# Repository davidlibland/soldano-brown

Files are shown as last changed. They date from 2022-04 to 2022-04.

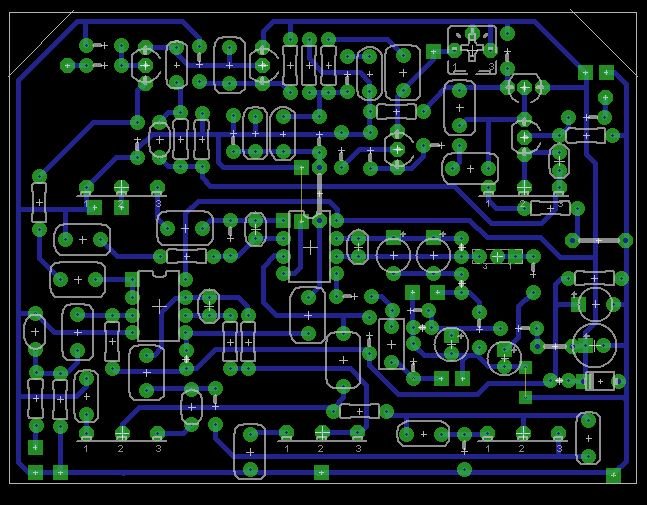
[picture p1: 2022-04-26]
SLO+MICRO.jpeg

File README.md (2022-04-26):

# Soldano BSIAB
This repo contains schematics and parts lists for a soldano clone based on the Brown Sound in a Box (BSIAB) pedal. It relies on cascading push-pull jfets.

It fits this enclosure: https://www.taydaelectronics.com/hardware/enclosures/matte-white-pedalpcb-125b-bare-drilled-enclosure-type-5-1.html

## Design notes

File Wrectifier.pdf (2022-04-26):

# Wrectifier

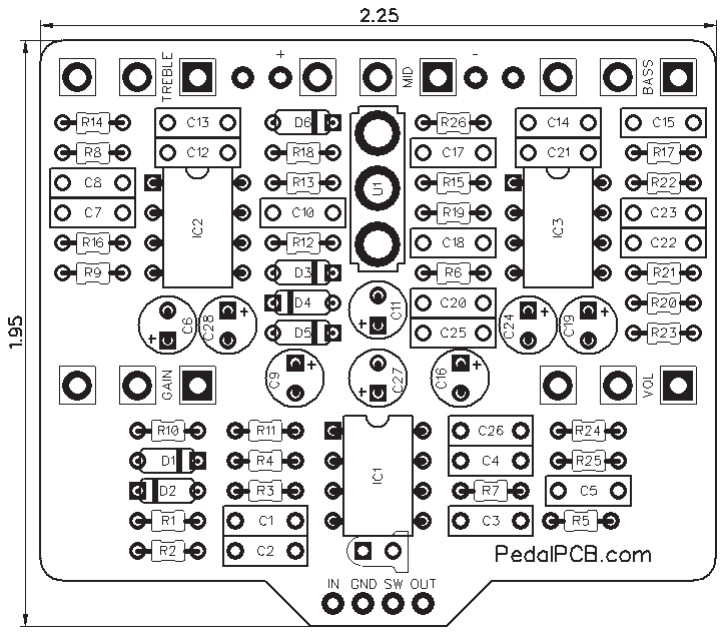
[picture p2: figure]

Copyright © 2017 - PedalPCB.com

R1 | 1M
R2 | 1K
R3 | 470K
R4 | 10K
R5 | 470K
R6 | 470K
R7 | 1K
R8 | 470K
R9 | 10K
R10 1K
R11 47K
R12 100K
R13 1K
R14 470K
R15 47K
R16 4K7
R17 1K
R18 10K
R19 47K

R20 33K
R21 33K
R22 680K
R23 10K
R24 10K
R25 10K
R26 4K7

Semiconductors
IC1 TL072
IC2 TL072
IC3 TL072
D1 | 1N4148
D2 | 1N4148
D3 | 1N4148
D4 | 1N4148
D5 | 1N4148
D6 | 1N5817
D7 | 3mm LED

Potentiometers
VOL | A100K
GAIN | A100K
BASS | C100K
MID | A100K
TREBLE | A50K

Revision 02.23.19

Resistors
C1 | 220nF
C2 | 220pF
C3 | 33nF
C4 | 560pF
C5 | 220nF
C6 | 1uF
C7 | 220pF
C8 | 220nF
C9 | 1uF
C10 220pF
C11 1uF
C12 4.7nF
C13 47nF
C14 47nF
C15 100nF
C16 1uF
C17 470pF
C18 47nF
C19 1uF

C20 100nF
C21 47nF
C22 1nF
C23 330pF
C24 1uF
C25 4.7nF
C26 10nF
C27 100uF
C28 10uF

Capacitors

Switches
Vintage/Modern SPDT Toggle

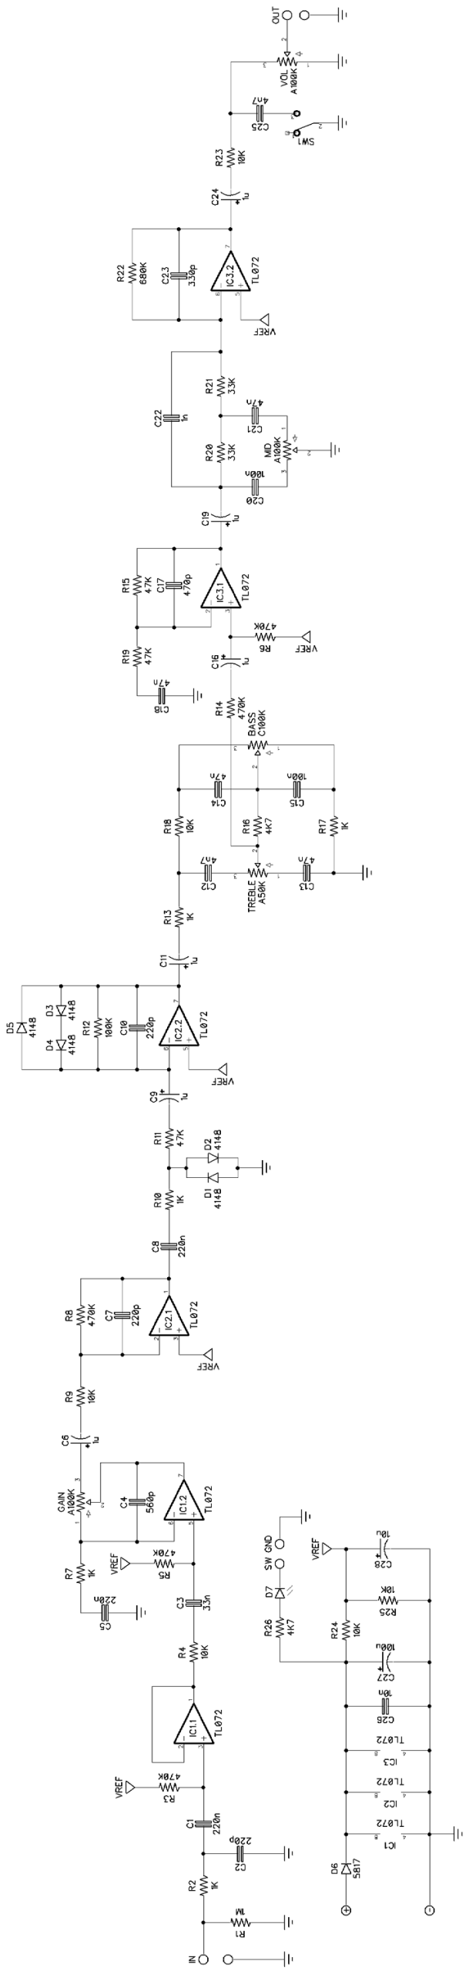
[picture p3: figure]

# Wrectifier

Copyright © 2017 - PedalPCB.com

# Wiring Diagram

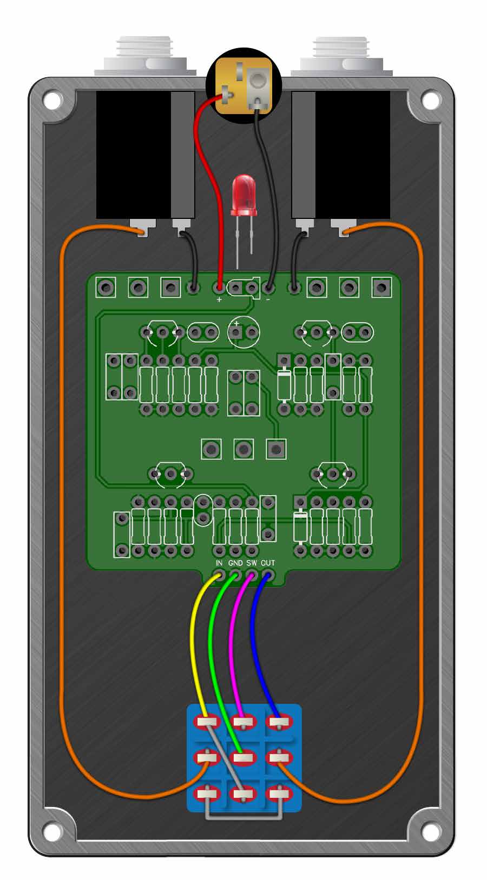
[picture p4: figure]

# Drill Template

# 4S125B enclosure with top mounted jacks

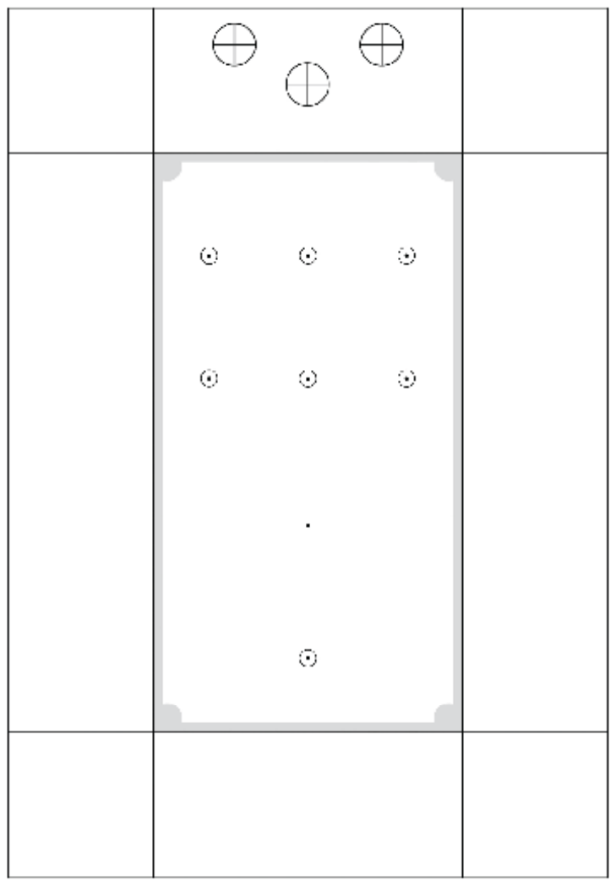
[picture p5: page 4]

5 x 1K
2 x 4K7
6 x 10K
2 x 33K
3 x 47K
1 x 100K
5 x 470K
1 x 680K
1 x 1M

3 x 220pF
1 x 330pF
1 x 470pF
1 x 560pF
1 x 1nF
2 x 4.7nF
1 x 10nF
1 x 33nF
4 x 47nF
2 x 100nF
3 x 220nF
6 x 1uF
1 x 10uF
1 x 100uF

3 x TL072

5 x 1N4148
1 x 1N5817

1 x 3mm LED

1 x A50K
3 x A100K
1 x C100K
Resistors (1/8W) | Capacitors | Semiconductors | Potentiometers

# Bill of Materials

1 x SPDT

Switches

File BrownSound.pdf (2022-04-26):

# BSIAB2 (Brown Sound In A Box - Version2) Design by Ed Guidry

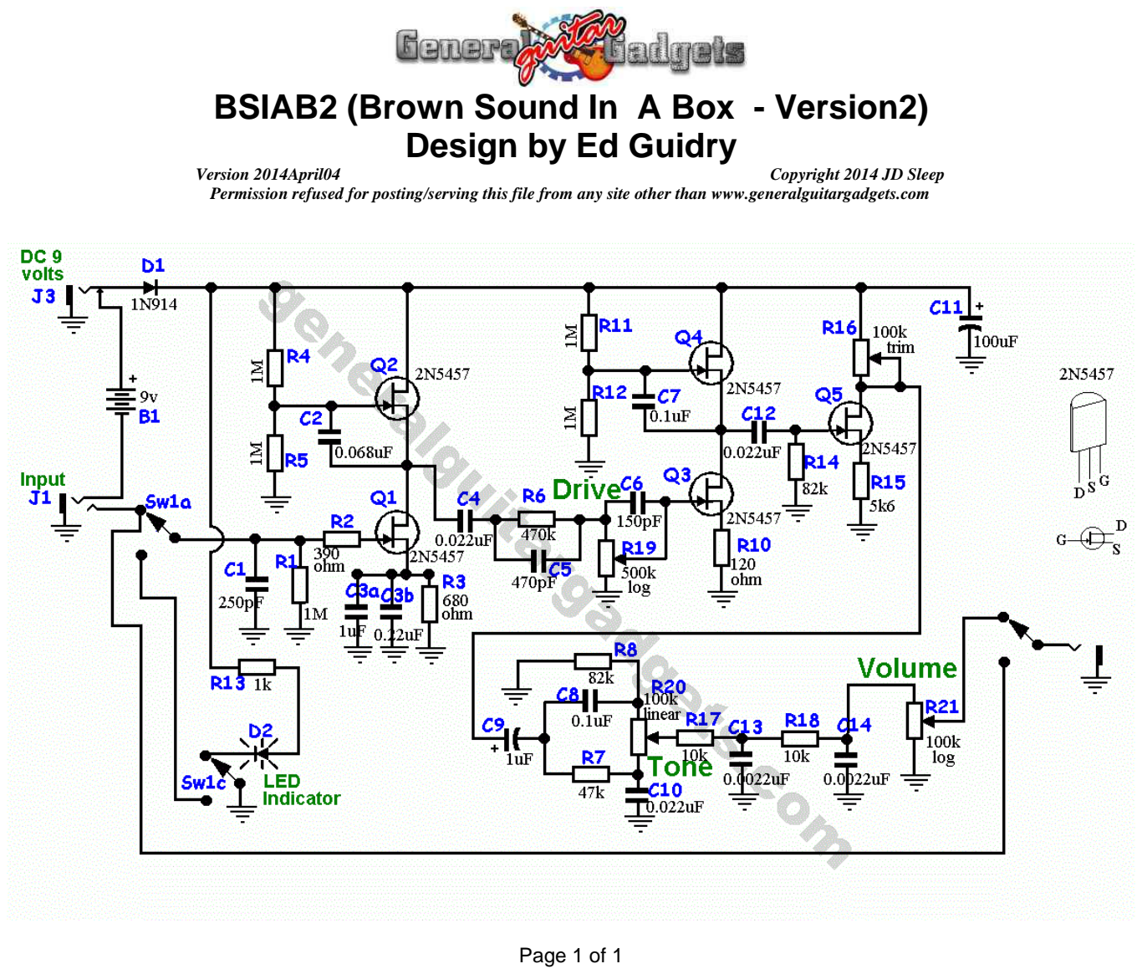
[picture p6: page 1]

Version 2014April04 | Copyright 2014 JD Sleep
Permission refused for posting/serving this file from any site other than www.generalguitargadgets.com

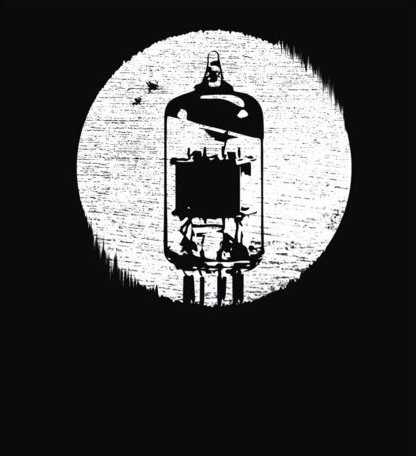
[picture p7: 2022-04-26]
small vacuum tube.jpeg

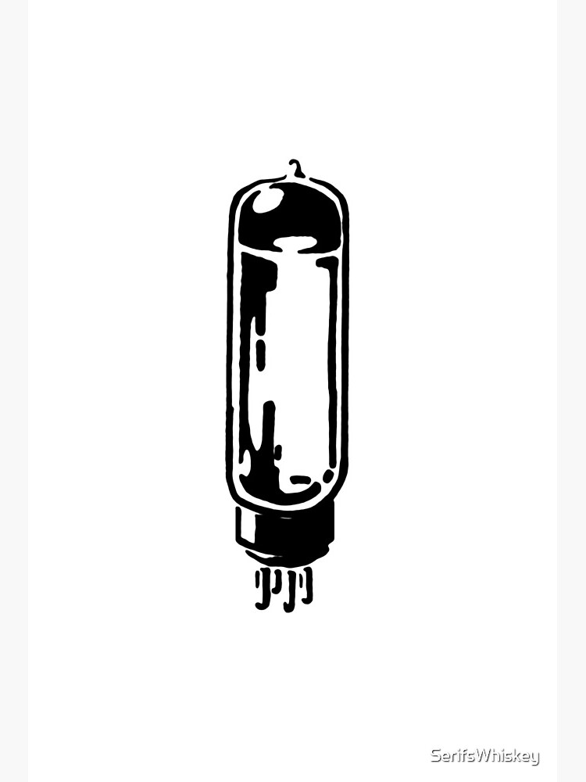
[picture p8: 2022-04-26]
el34.jpeg

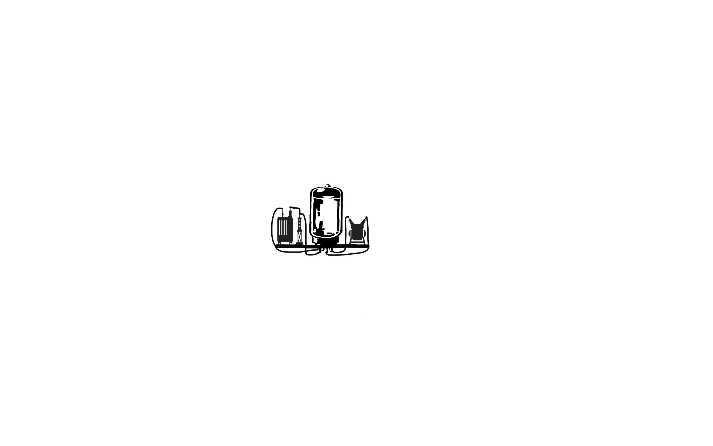
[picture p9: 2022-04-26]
velvet crush.jpeg

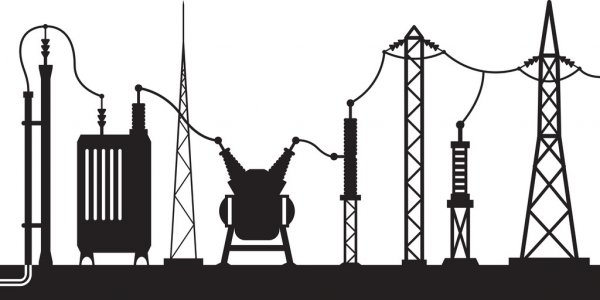
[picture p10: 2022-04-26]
transformer.jpeg

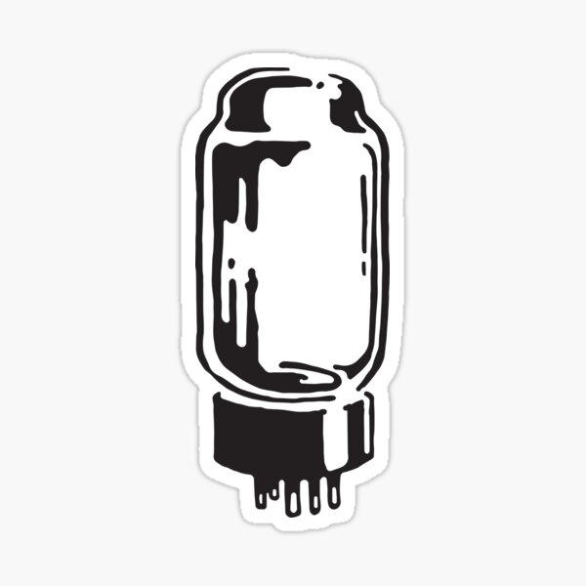
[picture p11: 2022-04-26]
12ax7.jpg

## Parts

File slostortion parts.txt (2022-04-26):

Partlist

Exported from slo.sch at 9/17/21 7:33 PM

EAGLE Version 9.6.2 Copyright (c) 1988-2020 Autodesk, Inc.

Assembly variant: 

Part     Value          Device       Package       Library               Sheet

+9V      +9V(T)         +9V(T)       SQUARE        gm-supply             1
BASS     C1M            POT16MM      16MM          gm-pots               1
C1       100pF          050X030_0502 050X030_050   gm-caps-ceramic       1
C2       0.1 uF         080X0452     080X045       gm-caps-film-chicklet 1
C3       1uF            080X0502     080X050       gm-caps-film-chicklet 1
C4       0.22 uF        080X0452     080X045       gm-caps-film-chicklet 1
C5       1 uF           070X0302     070X030       gm-caps-film-chicklet 1
C6       470pF          050X030_0502 050X030_050   gm-caps-ceramic       1
C7       1 uF           080X0502     080X050       gm-caps-film-chicklet 1
C8       0.47 uF        080X0452     080X045       gm-caps-film-chicklet 1
C9       0.1 uF         080X0452     080X045       gm-caps-film-chicklet 1
C10      470pF          070X0302     070X030       gm-caps-film-chicklet 1
C11      220 pF         075X0353     075X035_3     gm-caps-film-chicklet 1
C12      220pF          075X0353     075X035_3     gm-caps-film-chicklet 1
C13      1 uF           080X0502     080X050       gm-caps-film-chicklet 1
C14      0.01uF         050X030_0501 050X030_050_1 gm-caps-ceramic       1
C15      0.1 uF         080X0453     075X040_3     gm-caps-film-chicklet 1
C16      1 uF           080X0502     080X050       gm-caps-film-chicklet 1
C17      0.0047 uF      075X0352     075X035       gm-caps-film-chicklet 1
C18      10 nF          075X0352     075X035       gm-caps-film-chicklet 1
C19      470 pF         075X0302     075X030       gm-caps-film-chicklet 1
C20      0.0047 uF      075X0352     075X035       gm-caps-film-chicklet 1
C21      1 uF           080X0502     080X050       gm-caps-film-chicklet 1
C22      50p            050X030_0501 050X030_050_1 gm-caps-ceramic       1
C23      0.22 uF        080X0452     080X045       gm-caps-film-chicklet 1
C24      1uF            080X0502     080X050       gm-caps-film-chicklet 1
C25      100 pf         050X030_0501 050X030_050_1 gm-caps-ceramic       1
C27      22uF           050          050_020       gm-caps-electro-pol   1
C28      220uF          0631         063_025       gm-caps-electro-pol   1
D1                      1N400X.1     DO41-1        gm-diodes             1
D2       LED3MM         LED3MM       LED3MM        gm-diodes             1
GAIN     A500k          POT16MM      16MM          gm-pots               1
GND      GND(T)         GND(T)       SQUARE        gm-supply             1
IC1      TL072P         TL072P       DIL08         gm-ics                1
IC2      TL072P         TL072P       DIL08         gm-ics                1
IN       IN(T)          IN(T)        SQUARE        gm-supply             1
LED+                    PADO         ROUND         gm-supply             1
LED-                    PAD          SQUARE        gm-supply             1
MID      C50K           POT16MM      16MM          gm-pots               1
OUT      OUT(T)         OUT(T)       SQUARE        gm-supply             1
Q1       J201           J201         TO92-         gm-trans              1
Q2       J201           J201         TO92-         gm-trans              1
Q3       J201           J201         TO92-         gm-trans              1
Q4       J201           J201         TO92-         gm-trans              1
Q5       J201           J201         TO92-         gm-trans              1
R1       1k             3MM.2        R0204/2       gm-resistors          1
R2       1M             3MM.2        R0204/2       gm-resistors          1
R3       1M             3MM.2        R0204/2       gm-resistors          1
R4       10k            3MM.2        R0204/2       gm-resistors          1
R5       1M             3MM.2        R0204/2       gm-resistors          1
R6       1M             3MM.2        R0204/2       gm-resistors          1
R7       1M             3MM.2        R0204/2       gm-resistors          1
R8       4.7k           3MM.2        R0204/2       gm-resistors          1
R9       10k            3MM.2        R0204/2       gm-resistors          1
R10      1k             3MM.2        R0204/2       gm-resistors          1
R11      1M             3MM.2        R0204/2       gm-resistors          1
R12      1M             3MM.2        R0204/2       gm-resistors          1
R13      470k           3MM.2        R0204/2       gm-resistors          1
R14      1M             3MM.2        R0204/2       gm-resistors          1
R15      220k           3MM.2        R0204/2       gm-resistors          1
R16      470k           3MM.2        R0204/2       gm-resistors          1
R17      1k             3MM.2        R0204/2       gm-resistors          1
R18      1k             3MM.2        R0204/2       gm-resistors          1
R19      4.7k           3MM.2        R0204/2       gm-resistors          1
R20      100k           POTTRIM      B25P          gm-pots               1
R21      470k           3MM.2        R0204/2       gm-resistors          1
R22      220k           3MM.2        R0204/2       gm-resistors          1
R23      470k           3MM.2        R0204/2       gm-resistors          1
R24      22k            3MM.2        R0204/2       gm-resistors          1
R25      1k             3MM.2        R0204/2       gm-resistors          1
R26      220k           3MM.2        R0204/2       gm-resistors          1
R27      1M             3MM.2        R0204/2       gm-resistors          1
R28      6.8k           3MM.2        R0204/2       gm-resistors          1
R29      22k            3MM.2        R0204/2       gm-resistors          1
R30      100k           3MM.2        R0204/2       gm-resistors          1
R31      10k            3MM.2        R0204/2       gm-resistors          1
R32      47k            3MM.2        R0204/2       gm-resistors          1
R33      1M             3MM.2        R0204/2       gm-resistors          1
R34      6.8k           3MM.2        R0204/2       gm-resistors          1
R35      4.7k           3MM.2        R0204/2       gm-resistors          1
R36      22k            3MM.2        R0204/2       gm-resistors          1
SW_1                    DIP2         DIP2.B        switches              1
TREBLE   B500k          POT16MM      16MM          gm-pots               1
VOL      A100k          POT16MM      16MM          gm-pots               1

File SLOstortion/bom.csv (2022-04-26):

Qty | Value | Device | Package | Parts | Description
1 |  | 1N400X.1 | DO41-1 | D1 | Rectifier Diodes
1 | +9V(T) | +9V(T) | SQUARE | +9V1 | +9V Voltage Supply
2 | 0.0047 uF | 075X0352 | 075X035 | C17, C20 | 0.027 - 0.033uF
1 | 0.01uF | 050X030_0501 | 050X030_050_1 | C14 | 120 - 150pF
2 | 0.1 uF | 080X0452 | 080X045 | C2, C9 | 0.056 - 0.082uF
1 | 0.1 uF | 080X0453 | 075X040_3 | C15 | 0.056 - 0.082uF
2 | 0.22 uF | 080X0452 | 080X045 | C4, C23 | 0.056 - 0.082uF
1 | 0.47 uF | 080X0452 | 080X045 | C8 | 0.056 - 0.082uF
1 | 1 uF | 070X0302 | 070X030 | C5 | 0.0001 - .01uF (100 - 10,000pF)
4 | 1 uF | 080X0502 | 080X050 | C7, C13, C16, C21 | 0.1uF
1 | 10 nF | 075X0352 | 075X035 | C18 | 0.027 - 0.033uF
1 | 100 pf | 050X030_0501 | 050X030_050_1 | C25 | 120 - 150pF
1 | 100k | POTTRIM | B25P | R20 | Potentiometers
1 | 100pF | 050X030_0502 | 050X030_050 | C1 | 120 - 150pF
2 | 10k | 3MM.2 | R0204/2 | R4, R9 | 3mm Resistors
1 | 1K | 3MM.2 | R0204/2 | R17 | 3mm Resistors
10 | 1M | 3MM.2 | R0204/2 | R2, R3, R5, R6, R7, R11, R12, R14, R27, R33 | 3mm Resistors
4 | 1k | 3MM.2 | R0204/2 | R1, R10, R18, R25 | 3mm Resistors
2 | 1uF | 080X0502 | 080X050 | C3, C24 | 0.1uF
1 | 220 pF | 075X0353 | 075X035_3 | C11 | 0.027 - 0.033uF
3 | 220k | 3MM.2 | R0204/2 | R15, R22, R26 | 3mm Resistors
1 | 220pF | 075X0353 | 075X035_3 | C12 | 0.027 - 0.033uF
1 | 220uF | 631 | 063_025 | C28 | 33 - 220uF
3 | 22k | 3MM.2 | R0204/2 | R24, R29, R36 | 3mm Resistors
1 | 22uF | 50 | 050_020 | C27 | 0.22 - 100uF
1 | 33k | 3MM.2 | R0204/2 | R30 | 3mm Resistors
3 | 4.7k | 3MM.2 | R0204/2 | R8, R19, R35 | 3mm Resistors
1 | 470 pF | 075X0302 | 075X030 | C19 | 0.015 - 0.022uF
4 | 470k | 3MM.2 | R0204/2 | R13, R16, R21, R23 | 3mm Resistors
1 | 470pF | 050X030_0502 | 050X030_050 | C6 | 120 - 150pF
2 | 47k | 3MM.2 | R0204/2 | R31, R32 | 3mm Resistors
1 | 50p | 050X030_0501 | 050X030_050_1 | C22 | 120 - 150pF
2 | 6.8k | 3MM.2 | R0204/2 | R28, R34 | 3mm Resistors
1 | A100k | POT | POT | VOL | Potentiometers
1 | A500k | POT | POT | GAIN | Potentiometers
1 | B500k | POT | POT | TREBLE | Potentiometers
1 | C1M | POT | POT | BASS | Potentiometers
1 | C50K | POT | POT | MID | Potentiometers
1 | GND(T) | GND(T) | SQUARE | GND2 | Ground
1 | IN(T) | IN(T) | SQUARE | IN1 | Input
5 | J201 | J201 | TO92- | Q1, Q2, Q3, Q4, Q5 | N-channel JFET
1 | OUT(T) | OUT(T) | SQUARE | OUT1 | Output
2 | TL072P | TL072P | DIL08 | IC1, IC2 | OP AMP

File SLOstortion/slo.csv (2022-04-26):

Qty | Value | Device | Package | Parts | Description | SPICEPREFIX
1 |  | 1N400X.1 | DO41-1 | D1 | Rectifier Diodes
1 |  | DIP2 | DIP2.B | SW_1 | DIP 2-position
1 |  | PAD | SQUARE | LED- | PAD
1 |  | PADO | ROUND | LED+ | PAD
1 | +9V(T) | +9V(T) | SQUARE | +9V | +9V Voltage Supply
2 | 0.0047 uF | 075X0352 | 075X035 | C17, C20 | 0.027 - 0.033uF
1 | 0.01uF | 050X030_0501 | 050X030_050_1 | C14 | 120 - 150pF
2 | 0.1 uF | 080X0452 | 080X045 | C2, C9 | 0.056 - 0.082uF
1 | 0.1 uF | 080X0453 | 075X040_3 | C15 | 0.056 - 0.082uF
2 | 0.22 uF | 080X0452 | 080X045 | C4, C23 | 0.056 - 0.082uF
1 | 0.47 uF | 080X0452 | 080X045 | C8 | 0.056 - 0.082uF
1 | 1 uF | 070X0302 | 070X030 | C5 | 0.0001 - .01uF (100 - 10,000pF)
4 | 1 uF | 080X0502 | 080X050 | C7, C13, C16, C21 | 0.1uF
1 | 10 nF | 075X0352 | 075X035 | C18 | 0.027 - 0.033uF
1 | 100 pf | 050X030_0501 | 050X030_050_1 | C25 | 120 - 150pF
1 | 100k | 3MM.2 | R0204/2 | R30 | 3mm Resistors
1 | 100k | POTTRIM | B25P | R20 | Potentiometers
1 | 100pF | 050X030_0502 | 050X030_050 | C1 | 120 - 150pF
3 | 10k | 3MM.2 | R0204/2 | R4, R9, R31 | 3mm Resistors
10 | 1M | 3MM.2 | R0204/2 | R2, R3, R5, R6, R7, R11, R12, R14, R27, R33 | 3mm Resistors
5 | 1k | 3MM.2 | R0204/2 | R1, R10, R17, R18, R25 | 3mm Resistors
2 | 1uF | 080X0502 | 080X050 | C3, C24 | 0.1uF
1 | 220 pF | 075X0353 | 075X035_3 | C11 | 0.027 - 0.033uF
3 | 220k | 3MM.2 | R0204/2 | R15, R22, R26 | 3mm Resistors
1 | 220pF | 075X0353 | 075X035_3 | C12 | 0.027 - 0.033uF
1 | 220uF | 0631 | 063_025 | C28 | 33 - 220uF
3 | 22k | 3MM.2 | R0204/2 | R24, R29, R36 | 3mm Resistors
1 | 22uF | 050 | 050_020 | C27 | 0.22 - 100uF
3 | 4.7k | 3MM.2 | R0204/2 | R8, R19, R35 | 3mm Resistors
1 | 470 pF | 075X0302 | 075X030 | C19 | 0.015 - 0.022uF
4 | 470k | 3MM.2 | R0204/2 | R13, R16, R21, R23 | 3mm Resistors
1 | 470pF | 050X030_0502 | 050X030_050 | C6 | 120 - 150pF
1 | 470pF | 070X0302 | 070X030 | C10 | 0.0001 - .01uF (100 - 10,000pF)
1 | 47k | 3MM.2 | R0204/2 | R32 | 3mm Resistors
1 | 50p | 050X030_0501 | 050X030_050_1 | C22 | 120 - 150pF
2 | 6.8k | 3MM.2 | R0204/2 | R28, R34 | 3mm Resistors
1 | A100k | POT16MM | 16MM | VOL | Potentiometers
1 | A500k | POT16MM | 16MM | GAIN | Potentiometers
1 | B500k | POT16MM | 16MM | TREBLE | Potentiometers
1 | C1M | POT16MM | 16MM | BASS | Potentiometers
1 | C50K | POT16MM | 16MM | MID | Potentiometers
1 | GND(T) | GND(T) | SQUARE | GND | Ground
1 | IN(T) | IN(T) | SQUARE | IN | Input | I
5 | J201 | J201 | TO92- | Q1, Q2, Q3, Q4, Q5 | N-channel JFET
1 | LED3MM | LED3MM | LED3MM | D2
1 | OUT(T) | OUT(T) | SQUARE | OUT | Output
2 | TL072P | TL072P | DIL08 | IC1, IC2 | OP AMP

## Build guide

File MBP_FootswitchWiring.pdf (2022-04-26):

## Foot-switch wiring for Guitar Pedals

© madbeanpedals 11.05.2015

Beginners are often confused about how one should correctly wire a 3PDT foot-switch for true bypass operation. Most often, this is due to a lack of understanding of how the 3PDT switch operates. Let's fix that.

Standard Taiwan 3PDT foot-switch

fig.1

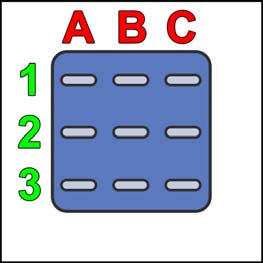
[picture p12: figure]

Fig.1 shows a bottom view of the 3PDT foot-switch.

What the? This thing has nine lugs! How can anyone keep track of what they all do? Well, it’s actually pretty easy. The 3PDT is nothing more than three SPDT switches sandwiched together.

fig.2

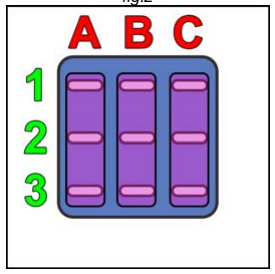
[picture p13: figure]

Fig.2 shows the 3PDT as three, independent SPDT switches.

Each SPDT switch is represented by columns A, B and C. In each switch, lug 2 is common. Lugs 1 and 3 are the two states of the switch. In other words, in one state the foot-switch connects lug2 to lug1. In the other state it connects lug2 to lug3. And, it does this simultaneously for all three switches.

fig.3

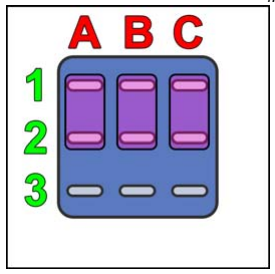
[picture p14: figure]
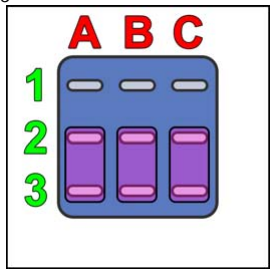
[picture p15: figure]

Fig.3 shows the two different “states” of the 3PDT foot-switch.

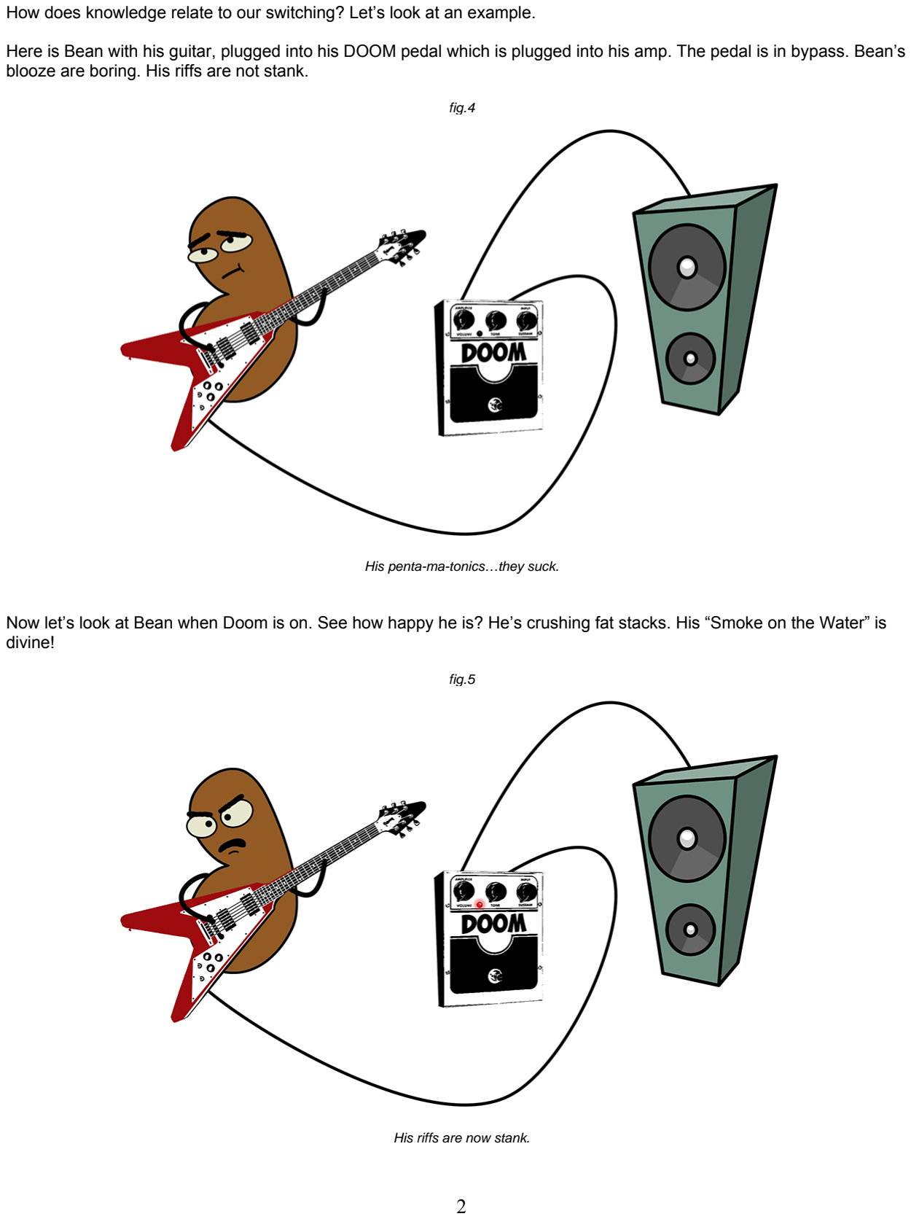
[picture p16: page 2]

How does knowledge relate to our switching? Let’s look at an example.

Here is Bean with his guitar, plugged into his DOOM pedal which is plugged into his amp. The pedal is in bypass. Bean’s blooze are boring. His riffs are not stank.

fig.4

His penta-ma-tonics…they suck.

Now let’s look at Bean when Doom is on. See how happy he is? He’s crushing fat stacks. His “Smoke on the Water” is divine!

fig.5

His riffs are now stank.

So, Bean has two states; just like our switch! Yes, I realize these illustrations were not necessary to make the point, but are you going to tell him that?
Now let’s look at a schematic representation of our bypass switching. Since the foot-switch has two “states” we should designate one as “on” and the other as “off”. On the 3PDT it doesn’t matter which set of lugs goes to which state, but generally we consider the “up” position (when lug2 and lug1 are connected) to be “on” and the down position (when lug2 and lug3 are connected) to be “off”.

fig.6

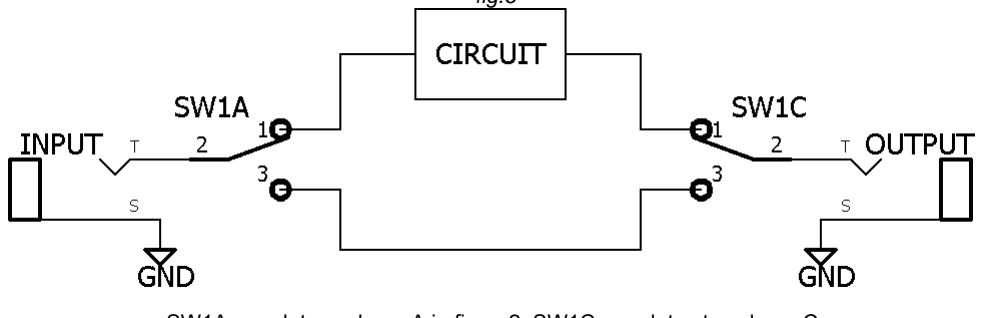
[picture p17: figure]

SW1A correlates column A in figure2. SW1C correlates to column C.
Hey, this is pretty easy! When SW1A and SW1C are in the up position, the input travels from lug2 to lug1 on SW1A and then to the input of the circuit. The output of the circuit goes to lug1/2 of SW1C and to the output. When it’s in the down position the input goes straight from SW1A lug2/3 to lug3/2 of SW1C and to the output. So, when it’s down it bypasses the circuit entirely eg. TRUE BYPASS.

Here is an illustration of how that is wired on a 3PDT

fig.7

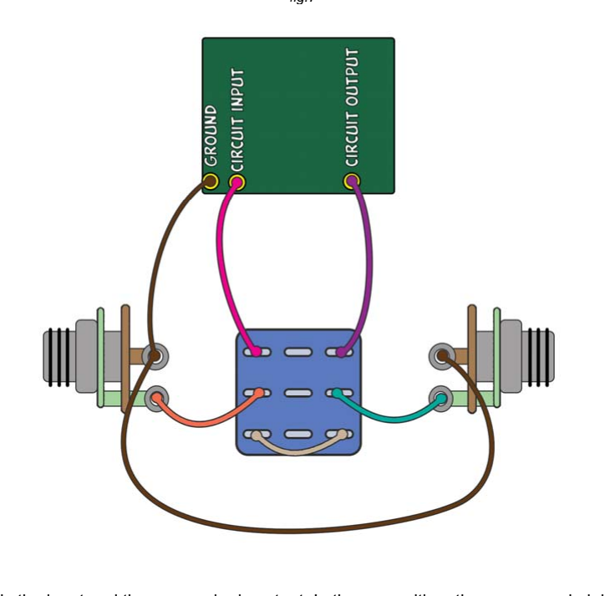
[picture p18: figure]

Here the orange wire is the input and the green wire is output. In the up position, the orange and pink wires are connected and the purple and blue wires are also connected. In the down position, the orange, beige and blue wires are connected to create our bypass. The sleeves of the two jacks are wired together which are then tied to a common grounding point on the circuit board.

But wait! What about an LED? Gotta know when the thing is on, after all. Easy enough. We left the middle SPDT switch unwired, so let’s use that to create an LED indicator.

Here is our typical LED sub-circuit. We supply +9v (or whatever DC voltage we are using for our effect) into a current limiting resistor which connects to the ANODE (+) of the LED. The CATHODE (-) of the LED is connected to ground and our LED lights up. The value of the resistor determines the overall brightness. 4k7 is generally a good value for diffused LEDs and 10k – 22k is good for super-bright, water clear LEDs.

fig.8

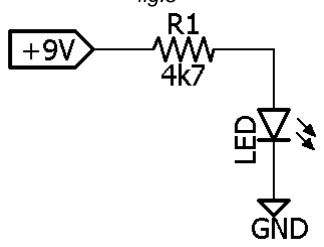
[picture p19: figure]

However, this isn’t quite right. If we connect it this way, our LED will always be on! We only want it to come on when the circuit is being used, not when it is bypassed. IOW, we want the LED activated when the foot-switch is in the “up” position. There are different ways to do this and the most common is to switch out the ground from the LED cathode to turn it off. Now our circuit looks like this:

fig.9

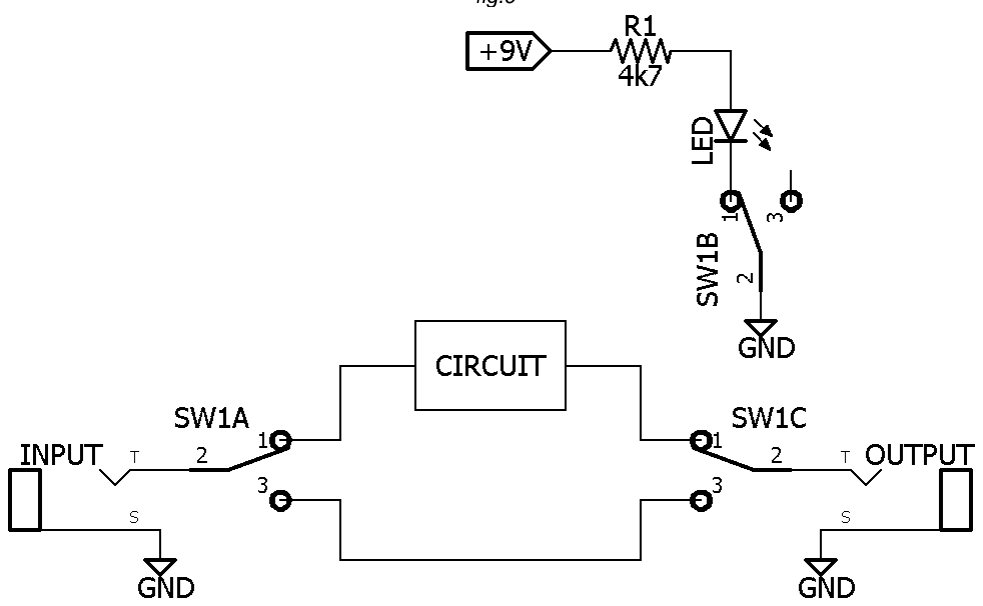
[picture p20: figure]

So, when our rows of lugs 1 and 2 are connected across the three SPDT switches in our 3PDT, the LED is connected to ground and lights up. When lugs 2 and 3 are connected, the ground from the LED is removed and the LED goes dark.

BTW: it doesn’t matter if we flipped SW1B and connected lug2 to the LED and lug1 to ground. The results would be the same. However, if we used lug3 instead of lug1, then our LED would actually light up in bypass instead!

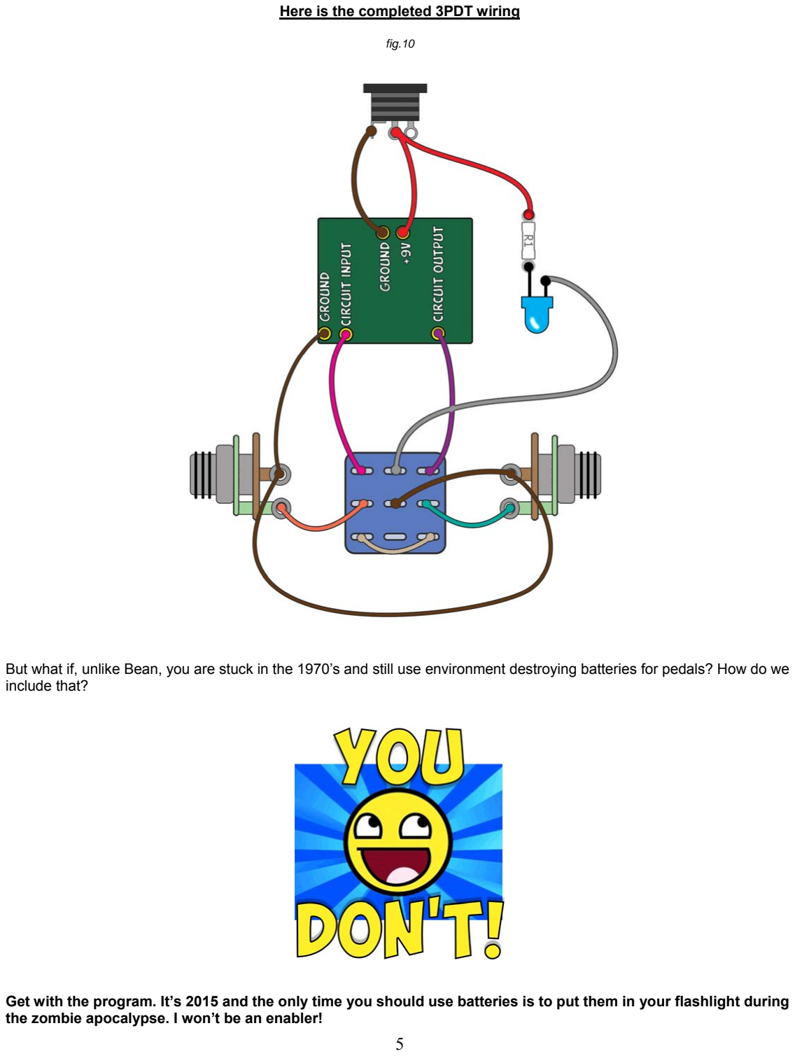
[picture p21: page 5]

Here is the completed 3PDT wiring

fig.10

But what if, unlike Bean, you are stuck in the 1970’s and still use environment destroying batteries for pedals? How do we include that?

Get with the program. It’s 2015 and the only time you should use batteries is to put them in your flashlight during the zombie apocalypse. I won’t be an enabler!

So this method is good, and it will work for 10/10 true bypass builds. But, could it be improved? Are there situations where this particular kind of bypass is not ideal? Turns out there are. Any circuit we are building that is very high gain, or particularly noisy can benefit from a better bypass. This is because unshielded wire can become microphonic in certain settings and even push noise into the bypass signal thereby ruining our true bypass efforts altogether.

To construct a better switch-based bypass we will use a technique to ground the circuit input when the effect is bypassed. This method does not always eliminate potential switching problems, but it gets us there most of the time. When we ground the circuit input, we’ve eliminated any signal bleed from propagating through the circuit. It also has the advantage that should our input coupling cap ever fail or become leaky then any DC voltage present at the circuit input will not dump right back into our guitar.

Here is a schematic drawing of an input grounding bypass

fig.11

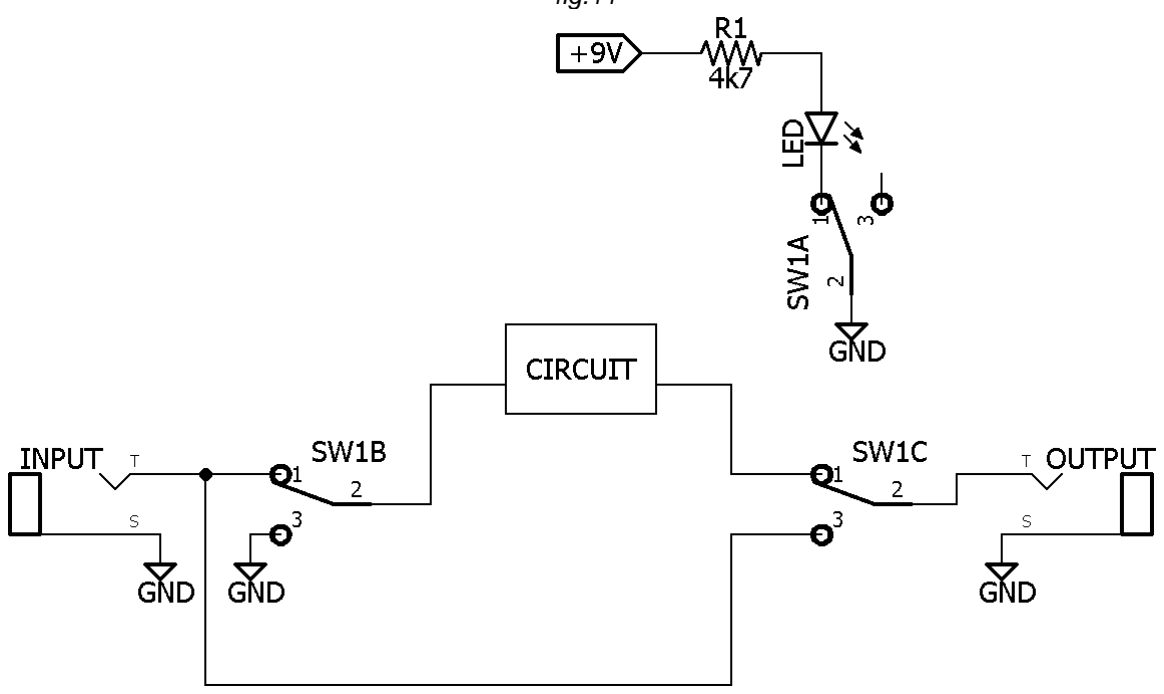
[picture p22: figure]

A bit more complicated but not too hard to follow. Let’s look.

SW1A and SW1B have been swapped on the input and LED. There’s a good reason for this which you will see in the wiring illustration below.

Our input is now connected to two places; SW1B lug1 and SW1C lug 3. Why? When our foot-switch is in the up position, the input connects to the circuit input, just like the previous wiring. Our input is also connected to lug3 of SW1C, but in the up position it is left open…it doesn’t connect to anything else. When the foot-switch is down, that input is now connected to lug2 of SW1C and thus the output. But, now the input of the circuit is grounded! Our LED still connects in the same way as before, just to a different SPDT in the 3PDT foot-switch.

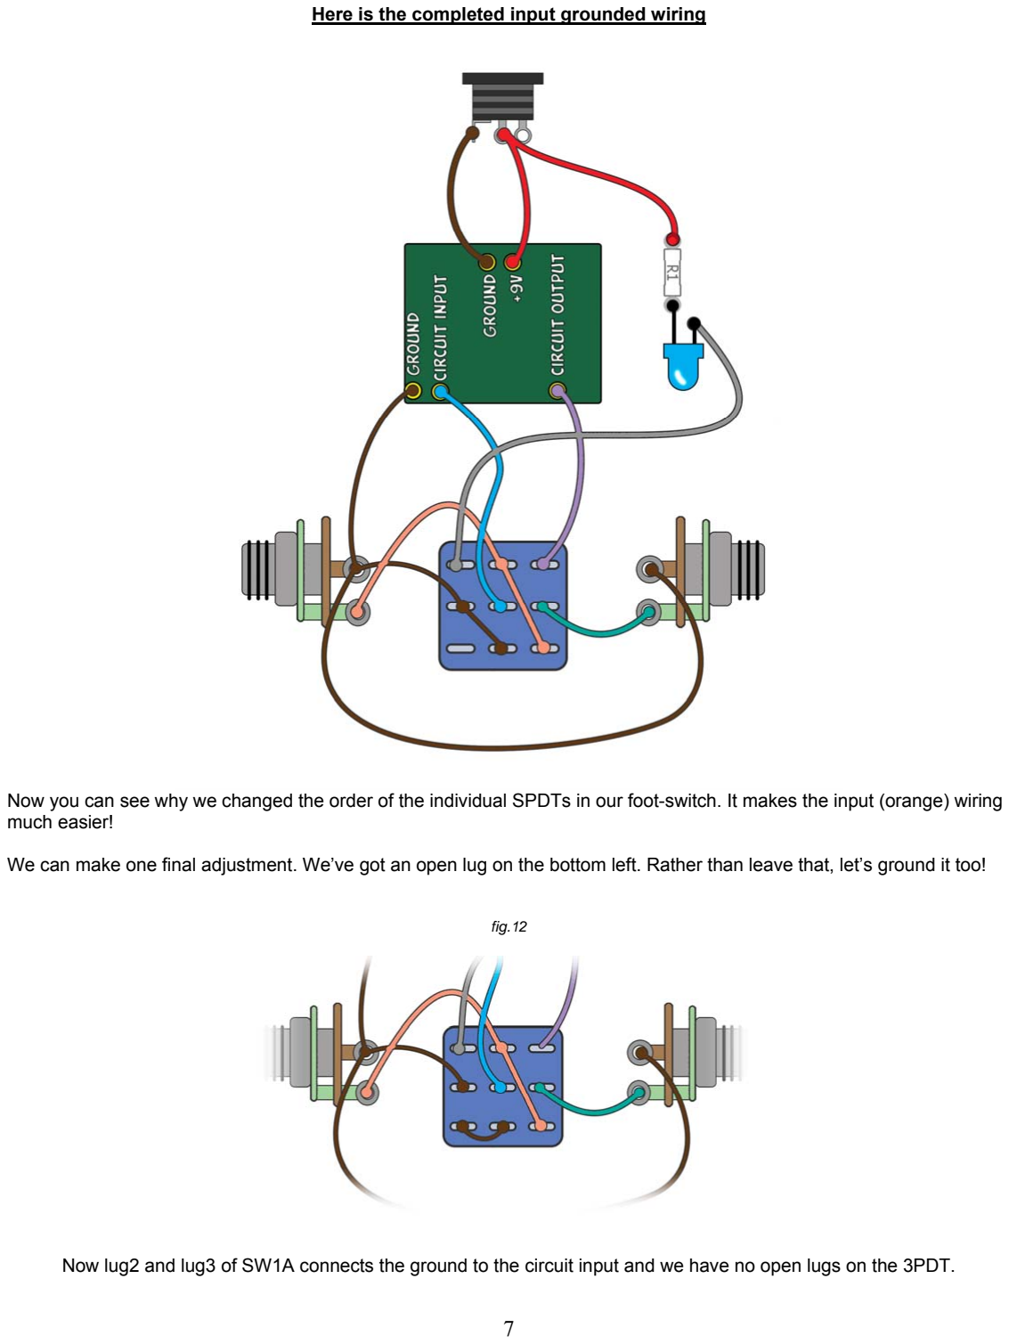
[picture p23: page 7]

Here is the completed input grounded wiring

Now you can see why we changed the order of the individual SPDTs in our foot-switch. It makes the input (orange) wiring much easier!

We can make one final adjustment. We’ve got an open lug on the bottom left. Rather than leave that, let’s ground it too!

fig.12

Now lug2 and lug3 of SW1A connects the ground to the circuit input and we have no open lugs on the 3PDT.

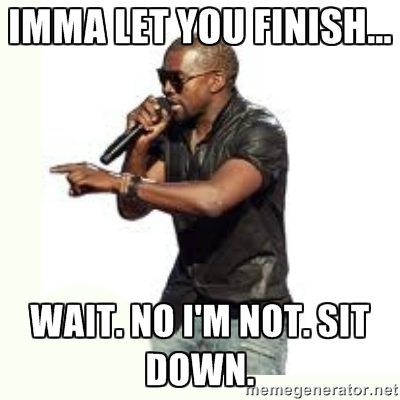
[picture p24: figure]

Let’s go even one step further! What if our 3PDT gets dusty and the connections get bad? How does that affect our switching? Well, it pretty much bones it, but you can at least keep the grounding intact in case of a switch failure. Just add one extra wire between lugs 2 and 3 of SW1A. The wire means the grounds stay connected even if our switch fails. PS I learned this trick from Marc Skreddy.

fig.13

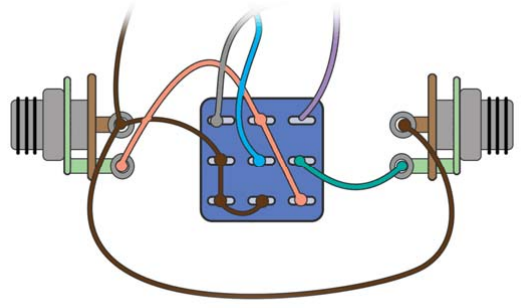
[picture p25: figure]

Bonus Round!

What do you do when you want to wire up two circuits in one box? Hey, it’s easy! So long as the circuits are independent of one another we can simply replicate the wiring we already have. The only change is that the output from the first 3PDT gets wired to the input of the second 3PDT and the output of the second circuit is also wired to the second 3PDT.

Here is the completed wiring for two circuits in one box

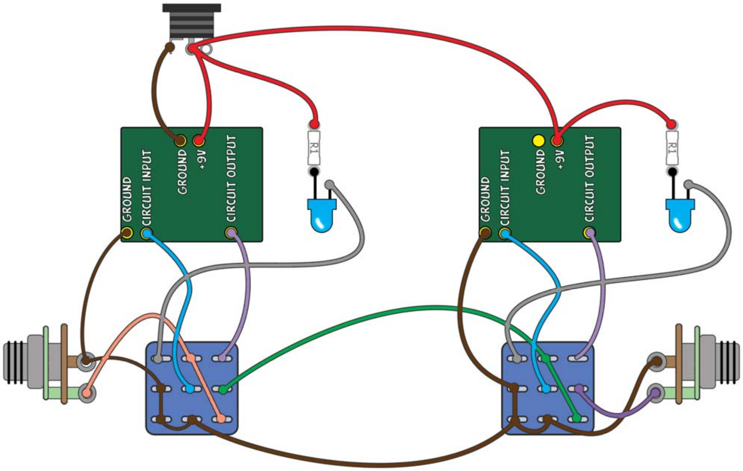
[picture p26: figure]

You might notice two things here:

1) There is no wire connecting the ground at the top of circuit 2. We don’t need it. We’ve already connected the ground to the circuit board from the second foot-switch. It doesn’t matter how you do it, just as long as one ground wire goes to that second circuit board and to the second switch.
2) There are two R1 resistors. That’s because I am lazy and did not generate a separate image labeled “R2” for the second LED.

Congratulations! You are now and expert in true bypass wiring for guitar pedals. I suggest mentioning this to your significant-other at least 4 times in the next 3 days. S/He will be thrilled!

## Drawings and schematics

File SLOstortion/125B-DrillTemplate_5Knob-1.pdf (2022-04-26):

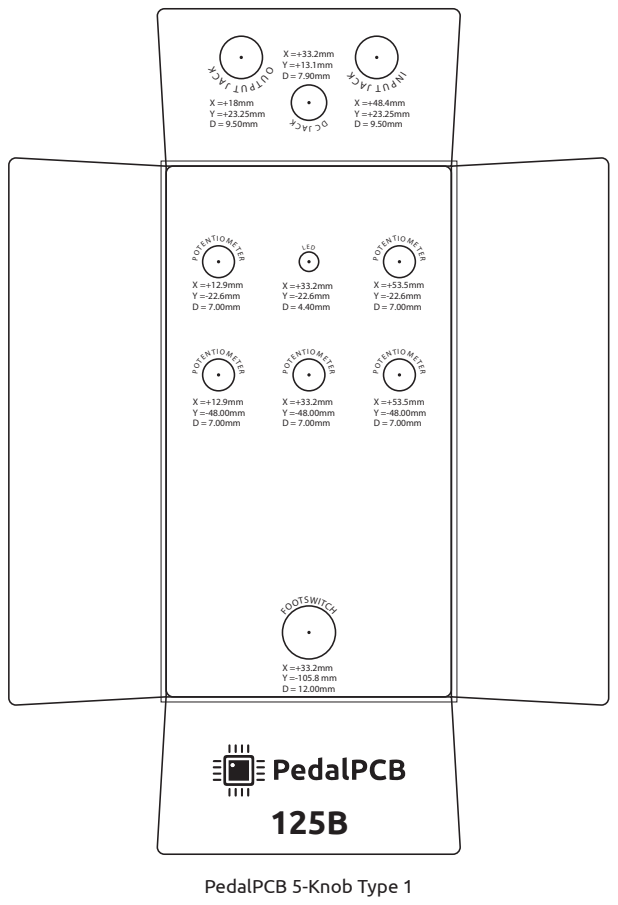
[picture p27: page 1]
FOOTSWITCH; POTENTIO M E TER; LED

OUT UP J T ACK

PedalPCB 5-Knob Type 1

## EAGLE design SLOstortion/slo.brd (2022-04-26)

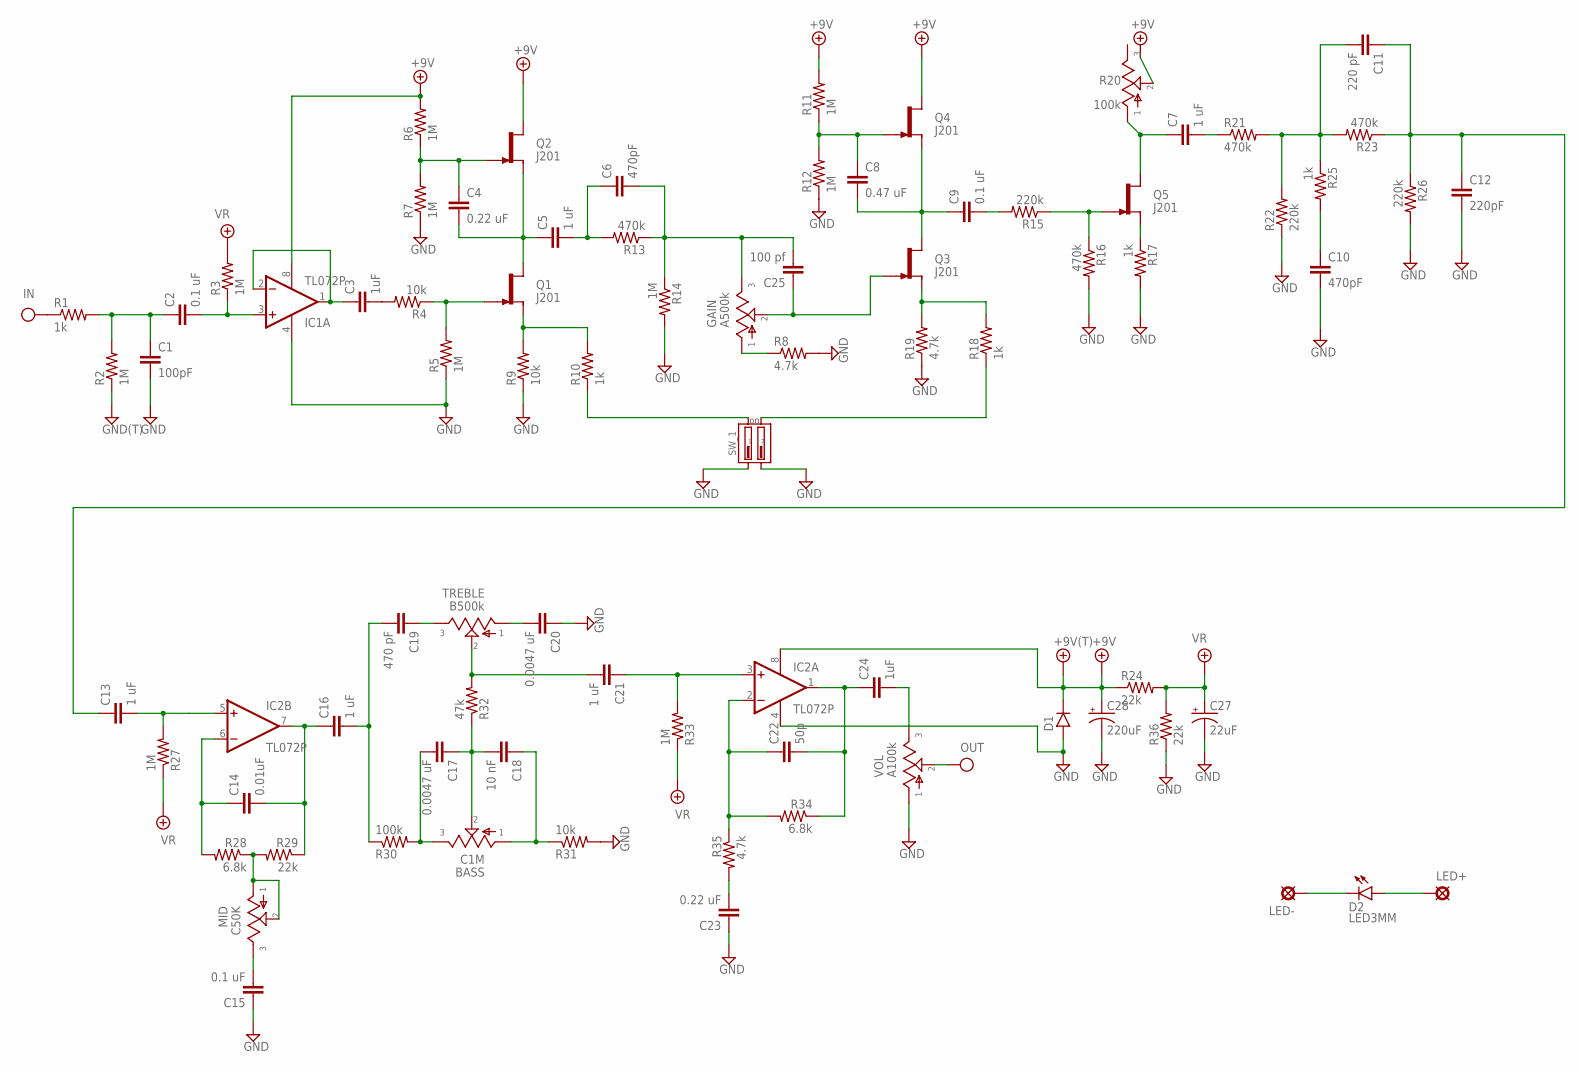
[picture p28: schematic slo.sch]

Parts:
+9V: +9V(T); SQUARE
BASS: C1M; 16MM
C1: 100pF; 050X030_050
C2, C9: 0.1 uF; 080X045
C3, C24: 1uF; 080X050
C4, C23: 0.22 uF; 080X045
C5: 1 uF; 070X030
C6: 470pF; 050X030_050
C7, C13, C16, C21: 1 uF; 080X050
C8: 0.47 uF; 080X045
C10: 470pF; 070X030
C11: 220 pF; 075X035_3
C12: 220pF; 075X035_3
C14: 0.01uF; 050X030_050_1
C15: 0.1 uF; 075X040_3
C17, C20: 0.0047 uF; 075X035
C18: 10 nF; 075X035
C19: 470 pF; 075X030
C22: 50p; 050X030_050_1
C25: 100 pf; 050X030_050_1
C27: 22uF; 050_020
C28: 220uF; 063_025
D1: 1N400X.1; DO41-1
D2: LED3MM
GAIN: A500k; 16MM
GND: GND(T); SQUARE
IC1, IC2: TL072P; DIL08
IN: IN(T); SQUARE
LED+: PADO; ROUND
LED-: PAD; SQUARE
MID: C50K; 16MM
OUT: OUT(T); SQUARE
Q1, Q2, Q3, Q4, Q5: J201; TO92-
R1, R10, R17, R18, R25: 1k; R0204/2
R2, R3, R5, R6, R7, R11, R12, R14, R27, R33: 1M; R0204/2
R4, R9, R31: 10k; R0204/2
R8, R19, R35: 4.7k; R0204/2
R13, R16, R21, R23: 470k; R0204/2
R15, R22, R26: 220k; R0204/2
R20: 100k; B25P
R24, R29, R36: 22k; R0204/2
R28, R34: 6.8k; R0204/2
R30: 100k; R0204/2
R32: 47k; R0204/2
SW_1: DIP2; DIP2.B
TREBLE: B500k; 16MM
VOL: A100k; 16MM

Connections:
+9V: +9V.1, C28.+, D1.C, IC1.8 (V+), IC2.8 (V+), Q2.3 (D), Q4.3 (D), R6.2, R11.2, R20.2, R24.1
GND: C1.2, C10.2, C12.2, C15.1, C20.1, C23.1, C27.-, C28.-, D1.A, GND.1, IC1.4 (V-), IC2.4 (V-), R2.1, R5.1, R7.1, R8.2, R9.1, R12.1, R14.2, R16.2, R17.2, R19.1, R22.1, R26.2, R31.2, R36.1, SW_1.P$1 (1), SW_1.P$3 (3), VOL.1
IN: IN.1, R1.1
unnamed: C1.1, C2.1, R1.2, R2.2
unnamed: C2.2, IC1.3 (+IN), R3.1
unnamed: C3.1, IC1.1 (OUT), IC1.2 (-IN)
unnamed: C25.1, GAIN.2, Q3.1 (G)
unnamed: C3.2, R4.2
unnamed: Q1.1 (G), R4.1, R5.2
unnamed: Q1.2 (S), R9.2, R10.2
unnamed: C5.2, C6.1, R13.2
unnamed: Q5.1 (G), R15.1, R16.1
unnamed: C6.2, C25.2, GAIN.3, R13.1, R14.1
unnamed: C10.1, R25.2
unnamed: Q3.2 (S), R18.2, R19.2
unnamed: C4.2, C5.1, Q1.3 (D), Q2.2 (S)
unnamed: GAIN.1, R8.1
unnamed: C8.2, C9.1, Q3.3 (D), Q4.2 (S)
unnamed: C4.1, Q2.1 (G), R6.1, R7.2
unnamed: C8.1, Q4.1 (G), R11.1, R12.2
unnamed: C9.2, R15.2
unnamed: Q5.2 (S), R17.1
unnamed: C7.1, Q5.3 (D), R20.1
unnamed: C7.2, R21.1
unnamed: C14.2, C16.1, IC2.7 (OUT), R29.1
unnamed: MID.1, MID.2, R28.1, R29.2
unnamed: C14.1, IC2.6 (-IN), R28.2
unnamed: C16.2, C19.2, R30.1
unnamed: C15.2, MID.3
unnamed: C11.1, C12.1, C13.1, R23.1, R26.1
unnamed: BASS.3, C17.2, R30.2
unnamed: D2.K (C), LED-.1
unnamed: C13.2, IC2.5 (+IN), R27.2
unnamed: BASS.1, C18.1, R31.1
unnamed: C11.2, R21.2, R22.2, R23.2, R25.1
unnamed: BASS.2, C17.1, C18.2, R32.1
unnamed: C19.1, TREBLE.3
unnamed: C21.2, R32.2, TREBLE.2
unnamed: C20.2, TREBLE.1
unnamed: C21.1, IC2.3 (+IN), R33.2
unnamed: D2.A, LED+.1
unnamed: C22.1, IC2.2 (-IN), R34.2, R35.1
unnamed: C22.2, C24.1, IC2.1 (OUT), R34.1
unnamed: C23.2, R35.2
unnamed: R18.1, SW_1.P$4 (4)
unnamed: C24.2, VOL.3
unnamed: R10.1, SW_1.P$2 (2)
OUT: OUT.1, VOL.2
VR: C27.+, R3.2, R24.2, R27.1, R33.1, R36.2

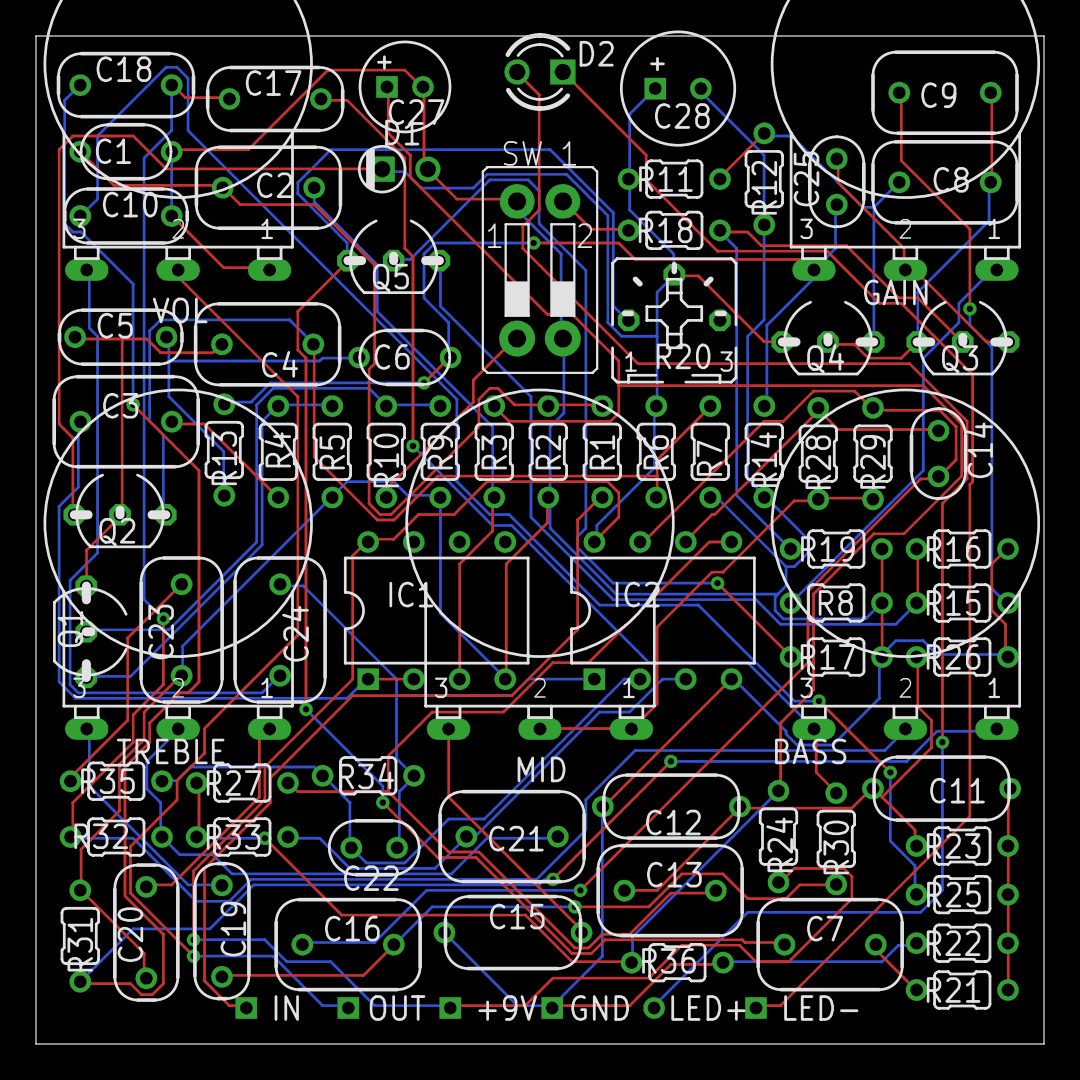
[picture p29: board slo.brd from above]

Board: 2 copper layers, 56.0 x 56.0 mm, 84 parts (0 on the bottom side), 49 nets.
